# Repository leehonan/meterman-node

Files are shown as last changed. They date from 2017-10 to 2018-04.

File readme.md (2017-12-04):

# Meterman MeterNode

This repo contains PCB designs and firmware for a low-cost, low-power, wireless LED pulse meter node.  It was designed to read and transmit energy consumption from an electricity smart meter LED pulses, but could be used for other LED pulse counting applications.  

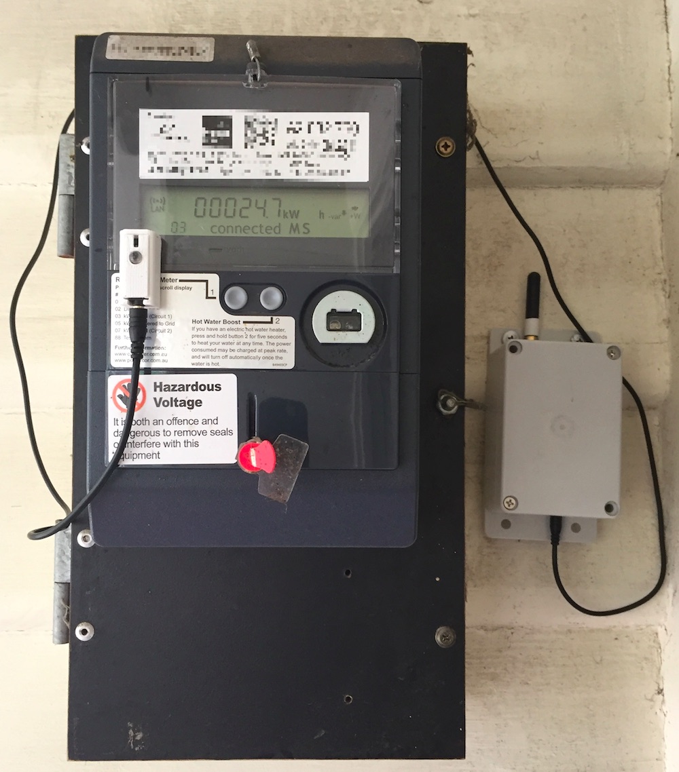
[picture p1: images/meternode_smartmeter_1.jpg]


This 'MeterNode' is part of a basic electricity monitoring system described at http://leehonan.com/meterman.  The 'MeterMan' system consists of:

* One or more MeterNodes, transmitting energy consumption at set intervals using sub-GHz packet radio (RFM69 @ 434/868/915MHz).

* A [Gateway](https://github.com/leehonan/rfm69-pi-gateway), being a Raspberry Pi 'Hat' that bridges the RFM69 network to a Raspberry Pi's UART Serial interface.

* A [Server](https://github.com/leehonan/meterman-server) that runs on the Pi, maintains energy consumption data, and provides access to this and other operational data through an API, a file journal, and a realtime socket API (socket API is TBD).

## This Repo

This (MeterNode) repo consists of:

* The MeterNode PCB design (authored in KiCad).  This mounts in a small 3D-printed box and is powered by 3xAA Batteries or a DC adapter.  It attaches to a small 'puck' sensor using a 3.5mm audio cable.

* The MeterNode Puck PCB design (also KiCad).

* 3D shape files (.STL) for the puck housing.

* Source code for the MeterNode firmware (AVR C with Arduino extensions).  

All contents are licenced according to the MIT licence.

## MeterNode Overview
The image below shows a partially-populated MeterNode installed in a project box with a 3xAA battery holder (empty space at bottom left due to omitting CT and DC power sub-circuits).

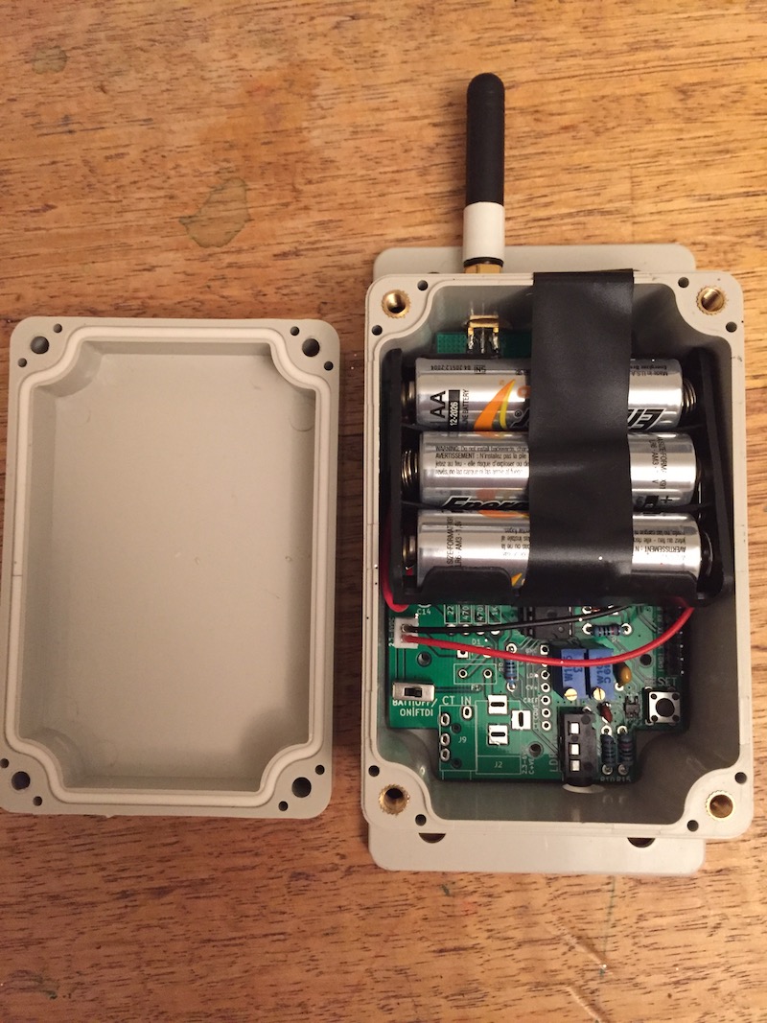
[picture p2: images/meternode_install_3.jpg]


The MeterNode's companion 'Puck' is a peripheral pulse sensor (not really in the shape of a puck - although that was the original idea).  It has a photoresistor on one side, and a red 'super bright' LED on the other.  The photoresistor is placed over the smart meter's 'consumption' LED, and connected to the monitoring MeterNode using a TRS or TRRS 3.5mm cable (with a 3.5mm TRRS jack on each PCB).  

<table><tr>
<td align="center">
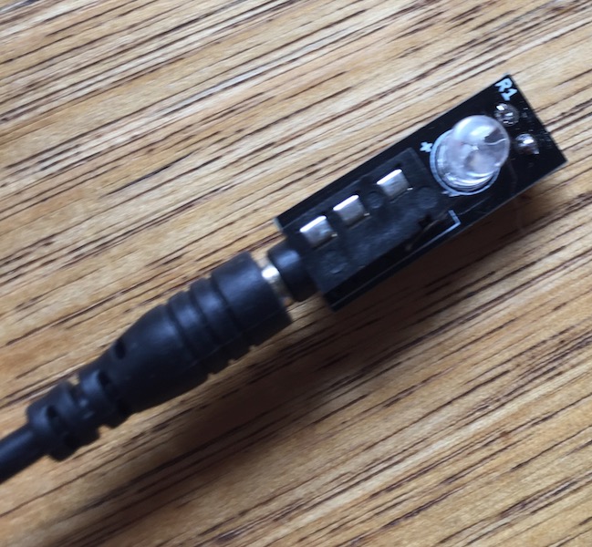
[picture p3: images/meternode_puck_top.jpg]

</td>
<td align="center">
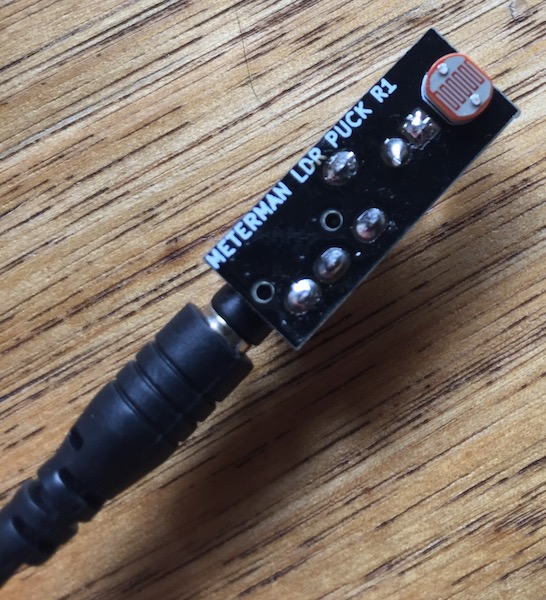
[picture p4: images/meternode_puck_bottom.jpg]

</td>
</tr></table>

The smart meter's consumption LED will pulse on/off as a particular unit of power is consumed (e.g. 1 pulse per watt-hour/Wh) - this varies by meter and is configurable on the MeterNode.  The puck's red LED can flash in unison with the smart meter (off by default to conserve battery).

While there are a number of ways to interrogate a smart meter (e.g. ZigBee, Serial and Optical ports), the approach used is cheap, non-invasive, hacker-friendly, and 'permissionless'.  Zigbee is not cheap, not hacker-friendly, and requires multiple permissions (including a Zigbee production cert and utility device authorisation).  Optical ports vary by meter and are usually password-protected.  Many meters do not have serial ports.

Later iterations may include direct wired metering ('behind' the smart meter) and additional CT clamps.

The MeterNode itself comprises:
* A DC power sub-circuit, switchable between battery/DC jack (3VDC to 5VDC) and FTDI (or off if no FTDI connection).  Uses a MCP1700 regulator to supply 3.3VDC.  Includes an upstream voltage divider for reading VIN or battery voltage (giving an indication of the battery's remaining charge).

* An ATMega 328P MCU sub-circuit, along the lines of common 'minimal low-power Arduino' circuits.  FTDI Header for programming and control.

* A PCF2123 low-power RTC.

* A radio sub-circuit with an RFM69W module.  The design uses an RP-SMA connector, but the PCB also supports uFL or a wire antenna.

* A sub-circuit to integrate the Puck, with a nano-comparator to give a definitive low/high signal to the MCU.  Because this is a slow-moving signal a Schmitt Trigger is used to avoid oscillation (through hysteresis).

* A sub-circuit to integrate a CT clamp, as used by [OpenEnergyMonitor's emonTX](https://github.com/openenergymonitor/emontx3).  This may be left unpopulated and is probably not practical to use if mounting next to a smart meter which tends to be outside and some distance from the distribution board/panel, which is typically indoors (unless running a long cable to the Puck).

The following images show a fully-populated MeterNode, with a DC jack and CT Clamp, alongside a partially-populated MeterNode with neither.

<table><tr>
<td align="center">
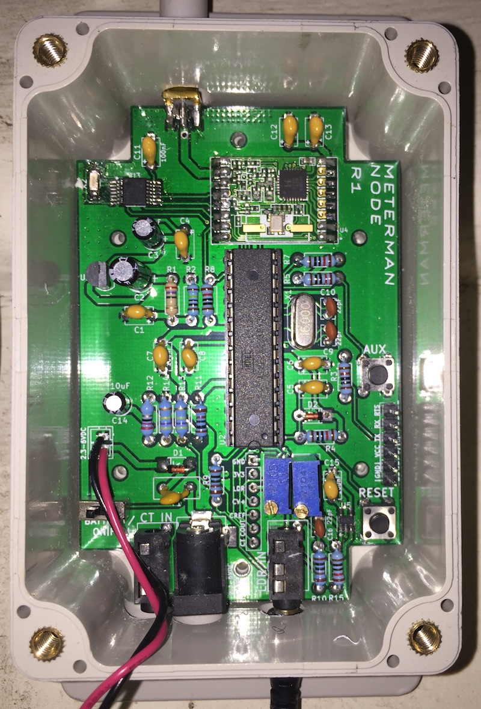
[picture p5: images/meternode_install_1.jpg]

</td>
<td align="center">
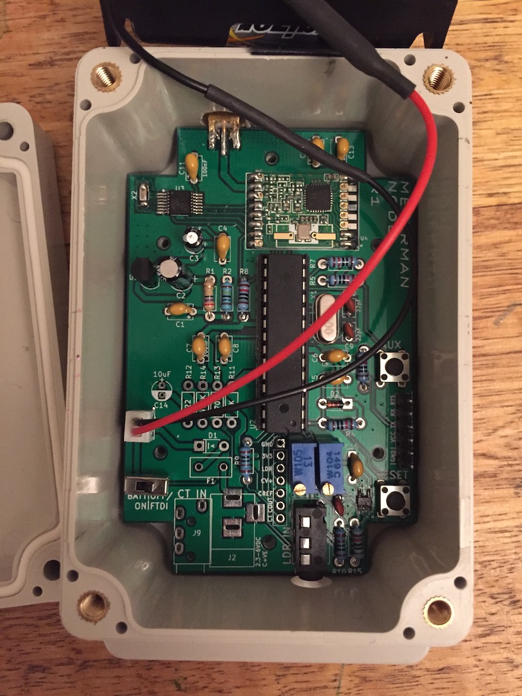
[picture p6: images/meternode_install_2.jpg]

</td>
</tr></table>

## Operation

The MeterNode 'sleeps' in normal operation (consuming about 80uA/microamps), with the MCU waking on an interrupt to record each meter LED pulse and send/receive messages as dictated by configurable timers.  

Given that it wakes/sleeps sporadically, the MeterNode initiates all two-way communication with the Gateway.  Configuration/control instructions to the MeterNode are effectively queued at the Gateway and despatched to the MeterNode when it requests 'Gateway Instructions' (GINR message).  While these instructions are usually polled for at a 'lazy' rate (e.g. every ten minutes), an aggressive polling instruction (GITR message) can be sent to cause the MeterNode to temporarily poll more frequently (e.g. every 30s for 5 min).

The Meternode's operation follows a loop:

* Wake up when an interrupt is triggered by an LED pulse. (At boot the Meternode will stay awake for 15s).

* Log the LED pulse with a timestamp from the onboard RTC, flashing the puck LED if configured.

* Check whether the current metering interval has expired (e.g. 30s), and if so, close it and begin a new one in the metering ring buffer (with a current reading from the CT clamp if configured).  Also check whether a 'meter update' message needs to be sent to the gateway.

* Check whether timers have expired for other periodic tasks, such as synchronising the RTC, adjusting Radio TX Power to fit target RSSI, or getting Gateway Instructions.  

* If required, check for an instruction from the gateway (passing status info such as battery voltage in the request) and process it.

* Sleep until the next LED pulse.

### Metering Approach & Limitations

The MeterNode simply counts consumption LED pulses, and records these against interval entries, with timing according to its onboard clock (RTC).  The pickup/counting is 100% accurate if the sensor is setup properly and not subject to extreme light interference.  A cumulative meter value is stored and transmitted in each message, allowing for interval update message failures.

The MeterNode can be set to a notional 'base value' to track the smart meter being monitored.  This allows for easy verification that the MeterNode is tracking accurately, although it is difficult to align the two exactly as the smart meter will only display a coarse value (e.g. to the nearest 100 Wh).  This can be set using a serial command or radio message as described below.

In normal operation, the MeterNode will create/close interval entries every n seconds, and despatch these in 'meter update' messages to provide energy consumption snapshots.

In the unlikely case that the smart meter is dormant (i.e. 0Wh consumption), the MeterNode will sleep ad infinitum, but then wake and send an update message that may have skipped previous intervals.

The MeterNode will execute a 'rebase' any time its clock changes, or the meter's base value is reset.  This results in a 'rebase message' which instructs consumers that the time/energy basis of the accumulation meter has changed.  Rebases will occur when:

* The MeterNode is booted.

* The RTC is set.

* The base value of the accumulation meter is changed.

* The accumulation meter cycles from its maximum value (4.2 GWh) to 0 Wh.  (Note that smart meters themselves are occasionally zeroed/cycled arbitrarily, e.g. by remote firmware upgrades.)

The MeterNode cannot:
* Guarantee a message element for every 0Wh consumption interval, or indeed guarantee that any message will be sent/received successfully.

* Guarantee a rebase message will be received.  Consuming applications should alert on large increases or reversals in time/meter values.

* Maintain meter readings between reboots (that would necessitate constant writing to EEPROM, which degrades after ~100K writes).

* Check itself against the meter being tracked.

* Confirm that it is alive, or detect issues with its sensor (as it will be asleep) - although this can be done at the consuming node(s).

### MeterNode Hardware Interface
The MeterNode PCB has the following switches, buttons, headers, and adjustable components.  These are shown below.
<table><tr>
<td align="center">
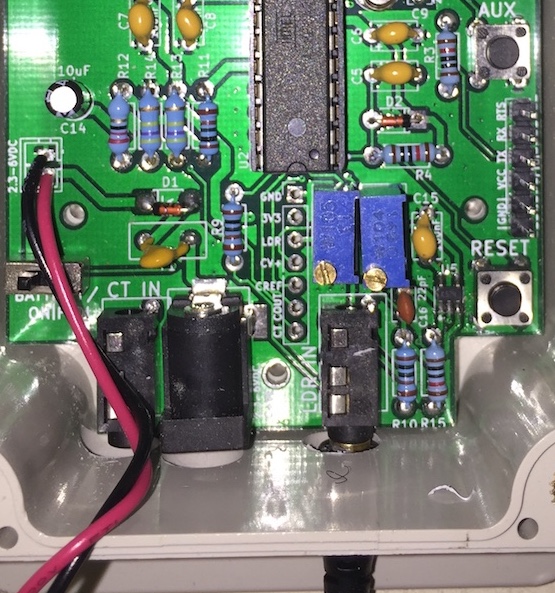
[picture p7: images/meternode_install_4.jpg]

</td>
<td align="center">
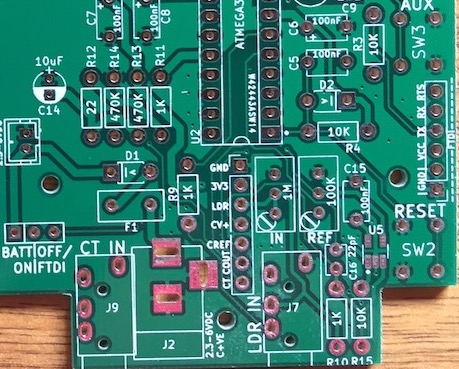
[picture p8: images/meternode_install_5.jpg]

</td>
</tr></table>

* A VIN switch that toggles between either battery/DC-in or FTDI/Off.  A battery must not be connected at the same time as a DC adapter, but either can be connected at the same time as a FTDI adapter.  If the switch is in the FTDI/Off position but FTDI is not connected the device will be off.  Conversely if the switch is in the battery/DC-in position but a FTDI adapter is connected, power will be drawn from the battery/DC adapter (with other FTDI functions working as normal).

* A MCU Reset button that reboots the MCU.

* An auxiliary button that is used to either toggle sleep mode or enable a temporary alignment mode:

    - If sleeping, any detected press will set sleep off (3 flashes).
    Release as soon as flashing starts.  Will need to hold down until
    interrupt fires (i.e. watched LED pulses).

    - If not sleeping, short press of < 1s will set sleep on (5 flashes).
    Release as soon as flashing starts.

    - If not sleeping, long press of > 3s will start a 60s adjustment mode (7
    flashes) that forces meter LED rate to 1, and time to 0 (mimic watched
    LED).  This will cause the Puck LED to flash in unison with the smart meter's LED for 60s.

* An FTDI header for use with a USB-FTDI adapter.  This is used to upload firmware and also to interact with the MCU directly over a serial connection (viewing events and using the MeterNode's command protocol to view information and change settings).  Firmware can be uploaded using avrdude directly, or via an IDE (such as platform.io).  Depending on the adapter and client software uses, this may reset the MCU.

* A breakout header that is used for setup and diagnosis, typically with a multimeter.  The positions are described below and pictured earlier:

| Position | Description |
| :--- |:---|
| GND | DC Ground. |
| 3V3 | 3.3VDC from regulator.  |
| LDR  | Output from LDR, fed to Comparator via Schmitt Trigger (from which it is segregated by a 1K resistor). <br> Tuned using the LDR trimpot, typically 0.2V to 2.0V (LED on-off). |
| CV+  | V+ input to Comparator, affected by Schmitt trigger feedback. |
| CREF  | LDR Comparator Reference Voltage (ideally 1.5V).  Set using the REF trimpot. |
| COUT | Output from Comparator.  Should be Low (0V) or High(3.3V).  Goes to MCU D3 (interrupt 1). | 
| CT | Output from CT clamp circuit.  Value from 0V to 3.3V is linear representation of RMS current.  Goes to MCU A1.  |

### Puck Setup
The setup and calibration of the light-dependent resistor (LDR) is critical.  It should be positioned directly over the LED being monitored, and shielded from ambient light.  It is best installed using double-sided tape to affix the base of the housing to the smart meter, ensuring that the LED is centred in the base's hole (that the photoresistor 'looks through').  See the assembly instructions below for more detail.

While the approach used is not overly sensitive to ambient light (compared with photodiodes, or an LDR without a comparator and schmitt trigger), minimising ambient light will increase the range around the comparator's reference/trigger point.  In practice the design used can work with some intrusion of relatively bright light (e.g. direct sunlight on a meter), but only up to a point.

With the MeterNode on and the puck installed, connected:
* Connect a multimeter to GND/CREF.  Adjust to 1.5V using the REF trimpot.

* Move the positive probe to the LDR breakout header position.  Adjust the LDR trimpot until you see a substantial swing between low and high states (e.g. 0.2V to 2.0V) around CREF.  A high level of ambient light may boost the lower value.  The trimpot's effective zone if fairly small - it will appear to be stuck high or low for many turns, and then suddenly become responsive.

* Move the positive probe to the COUT breakout header position.  This should be swinging between 0V (low) and 3.3V (high) to indicate reads.

Given that the actual hystersis gap of the comparator circuit is ~10mV, in theory a small swing either side of CREF will be sufficient to produce a definite high/low reading.  However, using a very wide value will compensate for fluctuations in ambient light and other factors.

### CT Clamp Setup
The design and firmware assumes a YHDC SCT-013-000 CT clamp, which has 100A max current.

A 22 Ohm burden resistor is used to output a voltage proportionate to CT clamp's secondary coil voltage.  

This configuration can measure up to 97A (23.3kW @ 240V).  The minimum reliable detection current is 0.3A, with potential for noise below this.  The constant CT_IRMS_HIGH_PASS is used to set a high-pass filter (0.3A by default).

WARNING: Be careful not to unplug the CT clamp from node while it's clamped to a 'live wire'.  It may shock.  There is a protection diode in the clamp, but its protection shouldn't be relied upon.

### Uploading Firmware
Firmware is uploaded using avrdude (alternately through an IDE such as atom/platform.io, the Arduino IDE may work too).  For an FTDI adapter with Id A403JXEV on OSX or Linux the command will be something like (change device and path to firmware):

```
sudo avrdude -c arduino -p atmega328p -P /dev/cu.usbserial-A403JXEV -b 115200 -U flash:w:/home/tmp/firmware.hex
```

### Serial Communication & Console
A serial connection can be made using a baud of 115200bps, 8N1 (8 data bits, no parity bit, 1 stop bit).  E.g. with minicom and a FTDI adapter at /dev/cu.usbserial-A403JXEV:

```
sudo minicom -b 115200 -o -D /dev/cu.usbserial-A403JXEV
```

Note that connecting or disconnecting a FTDI adapter will not cause a reboot when running on battery power.

The following commands are available through the serial console (case-insensitive):

| Command | Description |
| :--- |:---|
| help | Prints a list of commands. |
| z  | Toggles sleep on and off. |
| ctcl | Toggles CT Clamp on and off. |
| dump  | Prints (dumps) MeterNode config and status to the console.  |
| rcfg | Reset Config.  Resets configuration values stored in EEPROM to defaults and re-applies these.  |
| time | Prints current time from RTC. Set using time=[seconds since UNIX epoch, UTC] |
| logl | Prints log level - ERROR, WARN, INFO, DEBUG.  Set with logl=[log level]|
| ekey | Prints encryption key (16 byte AES) used by network participants for radio comms.  Set with ekey=[encryption key], e.g. ekey=CHANGE_THIS_ASAP|
| neti | Prints MeterNode's Network Id comprised of octets akin to an IP address but with an extra subnet (as the 4 octets define a subnet, with node addressing within this).  Set with neti=[network_id].  At least two octets need to be non-zero so 0.0.1.1 is the 'lowest' usable network subnet.  E.g. neti=0.0.1.1|
| gwid | Prints the 'node id' for the gateway.  This should be 1 by convention, but can be any unallocated address from 1 to 253. Set with gwid=[gateway Id]|
| noid | Print/set MeterNode's node id (set with noid=[node id]).  2-253 by convention. |
| trss | Print/set target RSSI for auto-tuning (set with TRSS=[target RSSI]).  Range is -100 (no signal) to 1 (almost no noise), 0 is disable auto-tuning. -75 is a reasonable value. |
| txpw | Print/set transmission power (set with TXPW=[tx power in dBi]).  For RFM69W range is -18 to +13, for RFM69HW is -14 to +20. Higher values will use more power. |
| mtrv | Set meter value (set with MTRV=[meter value]) in Wh.  May be used to track electricity meter's register. Will overflow and cycle to 0 at 4.2 billion Wh. |
| mtrr |  Print/set meter impulse per kWh rate (set with MTRR=[impulse count]).  E.g. mtrr=1000. |
| mtri |  Print/set meter interval (set with MTRI=[meter interval in sec]).  Up to 255. |
| test |  Toggle test mode, forcing sleep off and simulating watched meter LED pulses. |
| ledr |  Print/set puck LED rate (set with LEDR=[rate per meter LED]).  This is the number of 'watched meter' LED flash/pulses per 'puck' LED flash in response.  E.g. could flash once every 10 to consume battery.  0 means LED is disabled (except to indicate boot). |
| ledt |  Print/set puck LED time (set with LEDT=[time in millis]).  Is max duration of each LED pulse emitted by the puck in millis. Setting to 0 will cause to flash in unison with meter.  Maximum of 3000, but puck LED will always go low/off on falling edge of meter's pulse. |

###  Radio Protocol
The MeterNode uses the [RadioHead Library](http://www.airspayce.com/mikem/arduino/RadioHead/), and 'Reliable Datagrams' for all messaging.

Messages are AES-128 encrypted, with a maximum payload of 61 bytes.  Fields are comma-delimited, records semi-colon-delimited (only used for meter updates).

In addition to being encrypted, messages are contained within the 'subnet' created by the Network Id setting (e.g. 0.0.1.1), with each node having an identifier between 1 and 254 (255 is broadcast).  By convention I use 1 for a gateway, with nodes beginning at 2 (e.g. 0.0.1.1.2).

All datetimes are seconds since UNIX epoch (01/01/1970 00:00:00 UTC).

| Message | From | To | Description|
| :--- |:---| :--- |:---|
| Meter Update - with Current | node | gateway | Communicates the _n_ most recent closed meter intervals to the Gateway, with the meter's previous accumulated value (e.g. 100,000Wh), consumption in each interval (e.g. 15Wh), and an 'on the spot' current measurement taken at the end of the interval. <br> Format: `MUPC,<last_entry_finish_time>,<last_entry_meter_value>,{2..n of <interval_duration>,<interval_value>,<spot_rms_current>}` <br> Where in this case meter and interval values are in Wh (configurable) - with last entry value being a baseline accumulation entry (the last entry broadcast by the MeterNode) and interval values being increments to that, interval duration in seconds, current in Amps. <br> E.g.: `MUPC,1496842913428,18829393;15,1,10.2;15,5,10.7`  <br> Due to message size constraints this will contain no more than 2 interval entries.|
| Meter Update - no Current | node | gateway | As above, but without current measurements. <br> Format: `MUP_,<last_entry_finish_time>,<last_entry_meter_value>,{2..n of <interval_duration>,<interval_value>}` <br> E.g.: `MUP_,1496842913428,18829393;15,1;15,5;15,2;16,3` <br> The number of interval entries in each message can be set by a firmware constant, with 3 or 4 being a reasonable value.|
| Meter Rebase  | node  | gateway  | Sent at boot or whenever meter value or RTC adjusted to notify the gateway of step-changes in time or meter value.  'Re-baselines' the meter, such that all prior messages should be regarded as nominal/unreliable for determining an accumulation value. <br>Format: `MREB,<meter_time_start>,<meter_value_start>` <br> E.g.: `MREB,1496842913428,18829393`|
| Gateway Instruction Request  | node  | gateway  | Instruction Request to Gateway, including node status data. <br>Format: `GINR,<battery_voltage>,<uptime_secs>,<sleeptime_secs>,<free_ram>,<last_rssi>,<puck_led_rate>,<puck_led_time>,<meter_interval_time>,<meter_imp_per_kwh>`<br>E.g.:`GINR,4300,890000,555000,880,-80,10,100,5,1000` |
| Meter Instruction - Set Interval  | gateway  | node | Set accumulation meter interval. Note all such messages from the Gateway inform the node of the last RSSI for that node at the gateway (for use in TX Power auto-tuning).  <br>Format: `MINI,<new_interval>,<last_node_rssi>`<br>E.g.:`MINI,5,-70`  |
| Meter Instruction - Set Temporary Polling  | gateway  | node | Request from Gateway to temporarily increase GINR polling rate for a specified duration (secs). <br>Format: `GITR,<new_rate>,<duration>,<last_node_rssi>`<br>E.g.:`GITR,30,600,-70` |
| Meter Instruction - Set Value  | gateway  | node | Set accumulation meter value. <br>Format: `MVAI,<new_meter_value>,<last_node_rssi>`<br>E.g.:`MVAI,120000,-70`  |
| Meter Instruction - Set Puck LED  | gateway  | node | Set Puck LED pulse rate and duration. <br>Format: `MPLI,<led_pulse_rate>,<led_pulse_duration>,<last_node_rssi>`<br>E.g.:`MPLI,1,500,-70`  |
| Meter Instruction - 'No Op'  | gateway  | node | 'No op' ACK to GINR, provides RSSI for auto-tuning. <br>Format: `MNOI,<last_node_rssi>`<br>E.g.:`MNOI,-70`  |
| Clock Sync Request | node | gateway  | Clock Sync Ping Request to Gateway. <br>Format: `GMSG,<message>`<br>E.g.:`GMSG,BOOT v2. Flags: EX` |
| Clock Sync Response | gateway  | node | Clock Sync Ping Response from Gateway, used to sync local RTC. <br>Format: `PRSP,<request_time_node>,<current_time_gateway>,<align>,<last_node_rssi>`<br>E.g.:`PRSP;14968429155328,1496842915428,1,-70` |
| General-Purpose Message  | any  | any  | Broadcast to all devices in network.  Used to communicate boot event. <br>Format: `GMSG,<message>`<br>E.g.:`GMSG,BOOT v2. Flags: EX`|

**Interpreting Meter Updates**

The Meter Update Message should be interpreted as follows:
* Times are **inclusive**.  So consumption of 10Wh per 30s interval over 2 minutes from 10AM would be treated as:
    ```
    10:00:00 - 10:00:29 = 10Wh
    10:00:30 - 10:00:59 = 10Wh
    10:01:00 - 10:01:29 = 10Wh
    10:01:30 - 10:01:59 = 10Wh
    ```     

* last_entry_finish_time and last_entry_meter_value is for the last entry in the last MUP communicated by the meter node.  So for the example above, at 10:00:00 the interval entry ending at 09:59:59 was closed, and sent in a MUP with the 3 entries that preceded it.  At 10:00:00, 09:59:59 has just expired with an accumulated meter value of 5622Wh - these will form the baseline for the next MUP.

* Given this example, the next MUP is sent at 10:02:00 will be as follows:

    ```
    MUP_,1511737199,5622;30,10;30,10;30,10;30,10;
    ```

* Of course a MUP could be missed (without a rebase).  The consumer should take account of the baseline value, and not merely store/process the interval entries.    

### Power consumption & battery life
When awake the MCU consumes about 7mA/milliamps, and depending on radio config about 30-50mA for a few milliseconds when transmitting messages.  

In typical use, the MeterNode spends >=99% of its time asleep (affected by meter entry interval lengths).  

3xAA batteries should last 6-12 months with infrequent communication (TBC), although theoretically would last several years if sleeping perpetually, about 1-2 weeks if never sleeping.  A conservative meter interval (e.g. 60s), with 4 entries per message, and a long GINR polling interval (e.g. 600s) is recommended.

The MeterNode will function while battery voltage is >= 2.8V (or 2800mV as reported in GINR messages) - with the 328P MCU being the limiting factor, ideally supplied >=3.3V.  Unfortunately the regulator used (MCP1700) is only a step-down regulator - it cannot step-up lower voltages.  It is otherwise an excellent choice for this application.  Consuming applications should set a battery replacement alert threshold, e.g. 3.0V.

Using the puck LED (which consumes about 1mA) to indicate a meter LED flash will reduce battery life significantly - this should be minimised to testing, e.g. to check alignment (which can be performed more accurately with a multimeter).

## Implementation - MeterNode Firmware
For simplicity, the firmware is implemented as a single C++ program (no header file), although it will need supporting libraries to compile.  There is some redundancy versus the companion gateway firmware - the common components may be moved to a library.  Some Arduino library features are used.

The firmware requires a 328P that has been flashed with Optiboot.  It uses practically all of available program flash memory.  If you are hacking or debugging you'll need to comment out a block of code to make space - e.g. the checkButton() or checkTestMode() methods.

Depending on configuration, about 380 bytes RAM will remain free at runtime (on average, of 2K).  

There are a number of configuration settings at the beginning of the source code.  Particular attention should be paid to the 'Main Config Parameters'.

Note that a version is set in the firmware, and broadcast on boot.

The code is fairly well-documented so isn't covered further here.

## Implementation - PCBs & Cases

The MeterNode PCB measures 60x92mm and is designed to fit a widely-available [100x68x50mm 'project box'](https://www.banggood.com/White-Plastic-Waterproof-Electronic-Case-PCB-Box-100x68x50mm-p-948109.html), shown below.

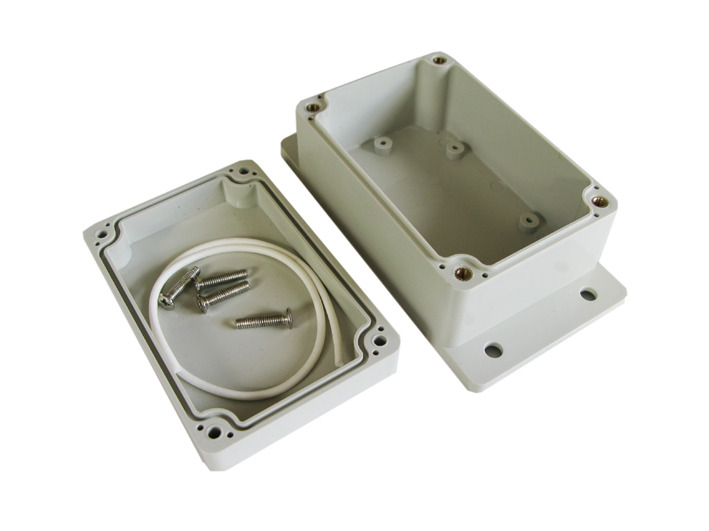
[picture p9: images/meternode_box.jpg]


The MeterNode's companion Puck PCB measures 15x20mm and can be mounted in a 3D-printed case (also in this repo).  The puck can be easily aligned with the meter's consumption LED by adhering the base/case only (positioning its hole directly over the LED) before completing the assembly.

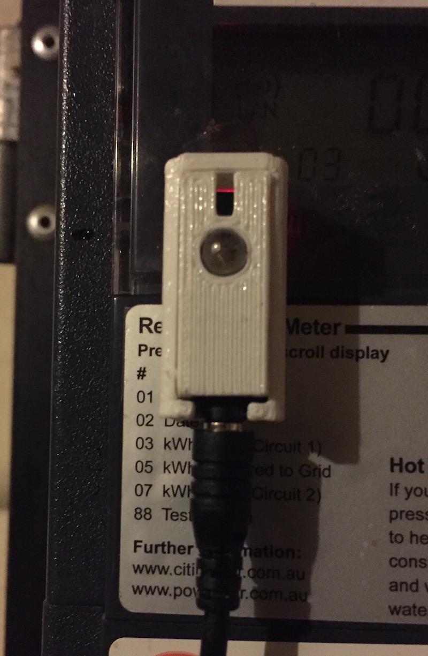
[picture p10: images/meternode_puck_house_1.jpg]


The images below show regular pucks both assembled and disassembled, along with an alternate puck configuration, where the black 'collet' piece shown (.STL included) can be used to position the LDR sensor in tight positions.  The protruding arm is used to adhere the sensor (e.g. using double-sided tape).  The particular meter that necessitated this was the iCredit 500 which has its LED tucked into a tight corner.

<table><tr>
<td align="center">
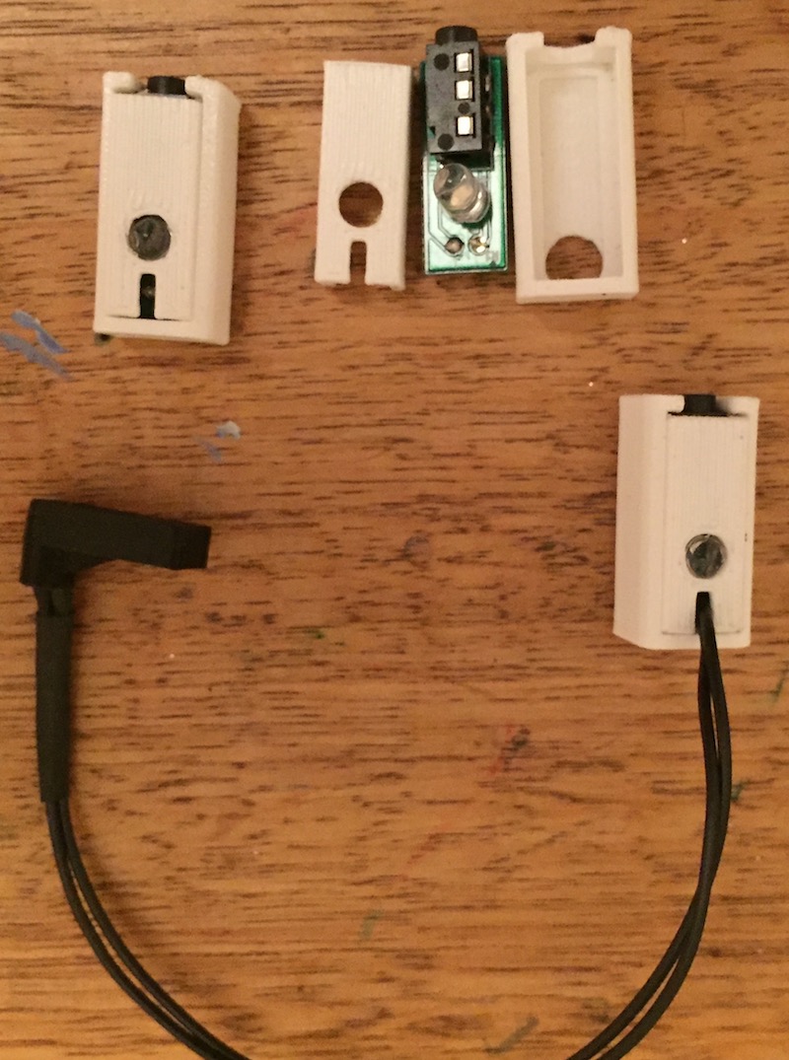
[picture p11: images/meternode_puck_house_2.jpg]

</td>
<td align="center">
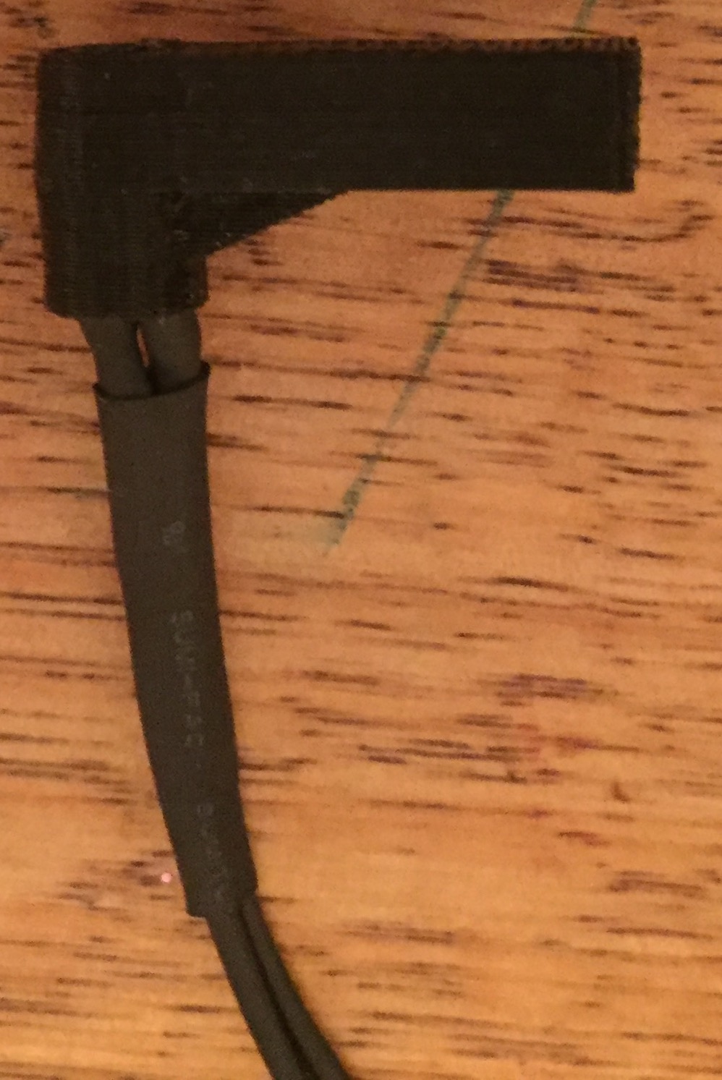
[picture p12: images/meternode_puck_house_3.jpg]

</td>
</tr></table>

The Puck Schematic & PCB is straightforward, so isn't discussed further here - except to mention that care should be taken when soldering as its small size means it can heat up quickly.  

### MeterNode Schematic & PCB

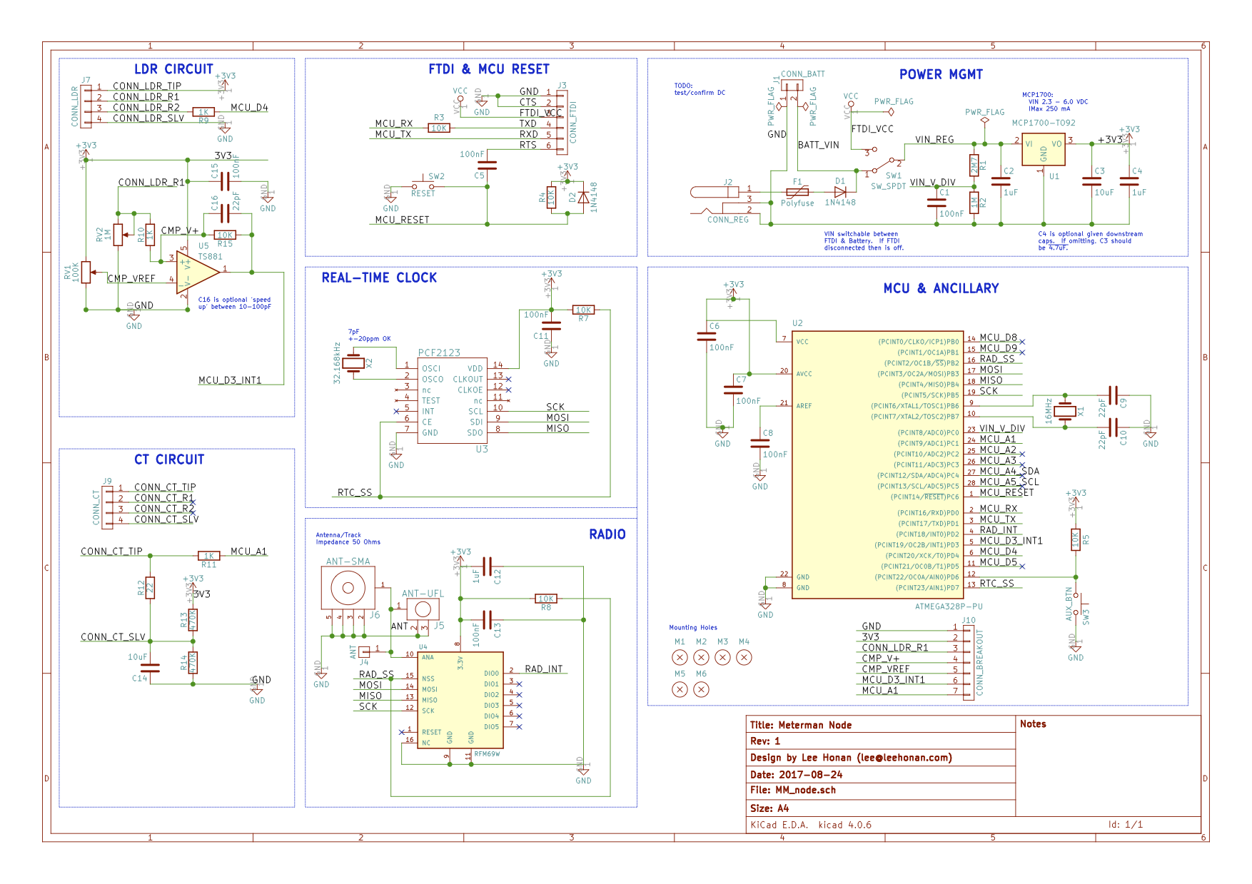
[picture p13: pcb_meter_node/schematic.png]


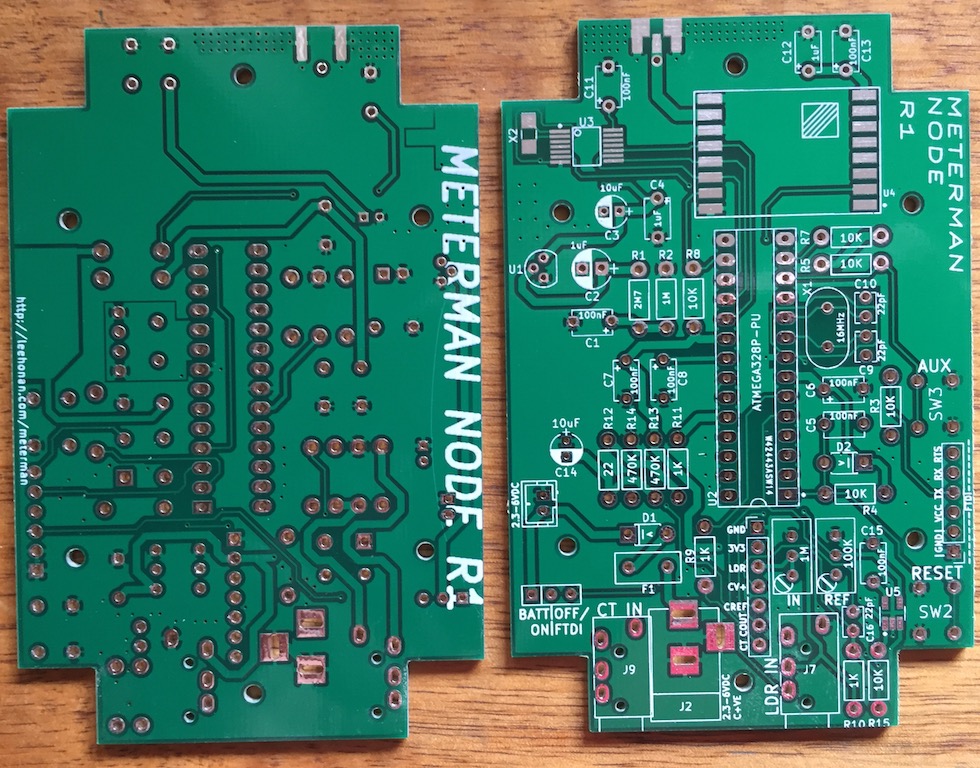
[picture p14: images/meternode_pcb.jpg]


The PCB design minimises the use of SMT components, and uses through-hole instead.  When I originally designed the board I wanted to make it 'hobbyist-friendly' with the only SMT component being the easily-solderable RFM69 and RP-SMA connector.  However in subsequent iterations I added the RTC and comparator, where the best choices were SMT.  This makes the board a hodge-podge, and annoying to make in volume (as I have had to for a few experiments). I may do an SMT-only variant in the future.

Highlights:
* The choice of a photoresistor (LDR) was made after a lot of research and experimentation.  Other projects have concluded that LDRs are too slow, or too affected by ambient light.  I found them to be better in terms of power consumption than alternatives such as photodiodes (about 1/10th), while offering a wide pickup range, and responding 'fast enough' (up to 10Hz).

* A TRRS jack is used for the puck and CT as I had a few hundred of these on-hand.  TRRS cables are unnecessary, TRS can be used.  R1 is not connected on the LDR jack, and R1 and R2 are not connected on the CT jack.
These could be hacked for another application.

* The MCP1700 regulator (3.3V) was chosen due to its low quiescent consumption (1.6uA).  I used a regulator because while the 328P and RTC tolerate VIN ~5.5VDC, the RFM69 has a maximum VIN of only 3.6VDC.  

* A voltage divider (consuming about 1.7uA) is used to measure the voltage input to the regulator - chiefly to allow a basic 'battery meter'.

* Any RFM69W or RFM69HW module will work.  I use the RFM69W because it can be tuned to use less TX power than the RFM69HW.  Given that there is no advantage to mixing radios, I use the RFM69HW on gateways because they are cheaper.

* The RTC used (PCF2123) has low quiescent power consumption (as low as 100nA) and is economical.  It needs a 32.768kHz crystal (7pF, +/- 20 ppm).

* The comparator used (TS881) has low quiescent power consumption (as low as 210nA), is simple to use, and is economical.

* The PCB design also contains a basic AC current sensing circuit for use with an optional CT clamp (around an active or neutral wire).  I used the design from [OpenEnergyMonitor](https://learn.openenergymonitor.org/electricity-monitoring/ct-sensors/how-to-build-an-arduino-energy-monitor-measuring-current-only).  This was a late addition to the design as I wanted to avoid looking at their well-established EmonTx project and see how I went my 'rolling my own'.  When I saw how easy the CT was too add I couldn't resist.  Of course, it will often be impractical to install alongside a smart meter unless running a long cable to the puck (as noted above).

The SMT/SMD components are mostly easy to solder with a decent iron and some flux.  The exception is the PCF2123 RTC, where it is very easy to bridge pins.  I suggest:
* doing SMDs first

* lightly tinning each pad, carefully aligning the IC and soldering a corner pin  

* then applying flux and working your way around

* using a multimeter to test for shorts - via easier to access pads (e.g. for 328P IC)

* inspecting with a loupe or magnifying glass

There are a number of videos on youtube on hand-soldering SMDs.

### Parts List

Includes CT clamp and DC jack.

Approx total is USD$35 (not including labour!).  That assumes you purchase common parts in quantity from Chinese suppliers (e.g. resistors, capacitors).  Otherwise cost will be radically higher.  

| Assembly | Part | Qty | Approx <br>Item Cost<br>(USD) | Comments |
| :--- |:---| :--- |:---|:---|
| Puck | PCB | 1 | $0.50 | E.g. 10 for $5 at PCBWay |
| Puck | Case | 1 | $0.50 | 3D-printed, PLA |
| Puck | LDR | 1 | $0.20 | 5MM Light-Dependent Resistor AKA Photo Resistor.  I use hamamatsu, much cheaper alternatives available. |
| Puck | LED | 1 | $0.02 | Super-bright 5mm, 20mA |
| Puck | TRRS Jack | 1 | $0.05 | PJ320D |
| Puck Cable | 3.5mm TRS or TRRS | 1 | $1.00 | No need to get TRRS |
| CT Clamp | YHDC SCT-013-000 | 1 | $8.50 | 100A version |
| MeterNode | PCB | 1 | $0.50 | E.g. 10 for $5 at PCBWay |
| MeterNode | Case | 1 | $3.50 | From Banggood, cheaper in bulk |
| MeterNode | RP-SMA 3dbi Antenna | 1 | $2.90 | I use higher quality ones via RocketScream, cheaper options available. |
| MeterNode | RP-SMA Connector | 1 | $0.50 |  |
| MeterNode | Battery Holder | 1 | $1.00 | Yet to find with JST connector so solder on cable, or directly to PCB. |
| MeterNode | AA Batteries | 3 | $2.00 | Use best you can afford, e.g. lithium |
| MeterNode | JST-PH connector set | 1 | $0.20 | Can solder wires directly. |
| MeterNode | TRSS Jacks | 2 | $0.05 | PJ320D |
| MeterNode | DC Barrel Jack | 1 | $0.10 | 2.1mm |
| MeterNode | PolyFuse | 1 | $0.20 | 50mA @60V, 5mm spacing |
| MeterNode | MCP1700 Regulator | 1 | $0.50 | 3.3V, TO-92 |
| MeterNode | MCU - ATMEGA 328P | 1 | $1.80 | DIP-28, with holder |
| MeterNode | 16MHz Crystal | 1 | $0.20 | |
| MeterNode | PCF2123 RTC | 1 | $1.20 | TSSOP1 |
| MeterNode | 32.768kHz Crystal | 1 | $0.50 | 7pF, +/- 20 ppm, 3.2x1.5mm SMD |
| MeterNode | RFM69W Module | 1 | $3.00 | SMD |
| MeterNode | TS881 | 1 | $0.65 | SOT-23-5 |
| MeterNode | Resistor - 22 Ohm | 1 | $0.01 | 0.25W |
| MeterNode | Resistor - 1 KOhm | 3 | $0.01 | 0.25W |
| MeterNode | Resistor - 10 KOhm | 6 | $0.01 | 0.25W |
| MeterNode | Resistor - 470 KOhm | 2 | $0.01 | 0.25W |
| MeterNode | Resistor - 1 MOhm | 1 | $0.01 | 0.25W |
| MeterNode | Resistor - 2.7 MOhm | 1 | $0.01 | 0.25W |
| MeterNode | Trimpot - 100 KOhm | 1 | $0.50 | Bourns 3296W knock-off |
| MeterNode | Trimpot - 1 MOhm | 1 | $0.50 | Bourns 3296W knock-off |
| MeterNode | Capacitor - 22 pF | 3 | $0.01 | Ceramic disc |
| MeterNode | Capacitor - 100 nF | 8 | $0.01 | Monolithic, Ceramic |
| MeterNode | Capacitor - 1 uF | 1 | $0.02 | Electrolytic |
| MeterNode | Capacitor - 1 uF | 2 | $0.01 | Monolithic, Ceramic |
| MeterNode | Capacitor - 10 uF | 2 | $0.02 | Electrolytic, 4x7mm |
| MeterNode | Diode - 1N4148 | 2 | $0.01 |  |
| MeterNode | Micro SPST Switch | 1 | $0.15 | 3P |
| MeterNode | 6x6mm pushbutton | 2 | $0.02 |  |
| MeterNode | Pin Header | 1 | $0.02 | 6P, 2.54mm pitch |

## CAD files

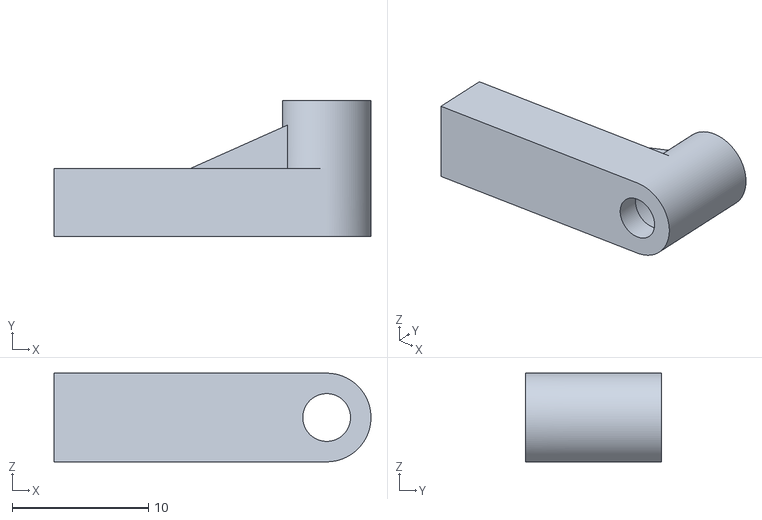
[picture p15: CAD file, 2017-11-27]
pcb_puck/3D parts/Collett.stl
23.2 x 10.0 x 6.50

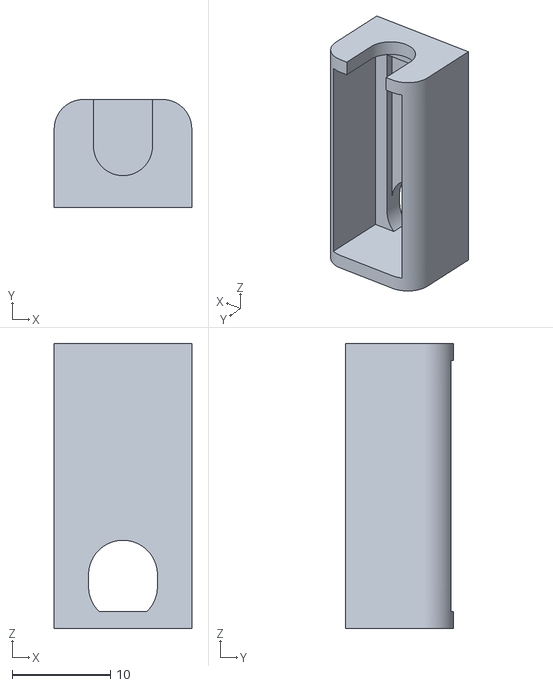
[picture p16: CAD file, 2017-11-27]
pcb_puck/3D parts/Base.stl
14.0 x 11.0 x 29.0

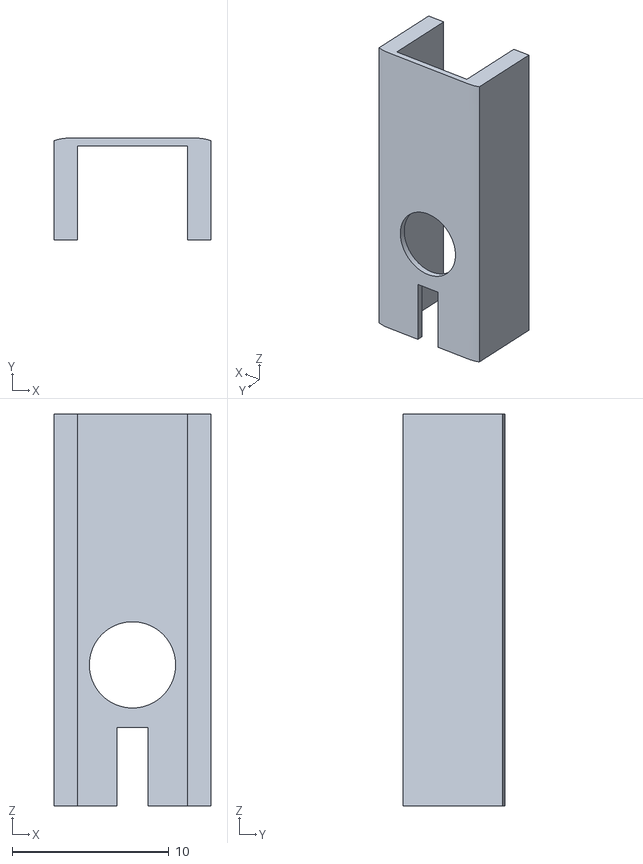
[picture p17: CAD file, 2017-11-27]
pcb_puck/3D parts/Lid.stl
10.0 x 6.50 x 25.0

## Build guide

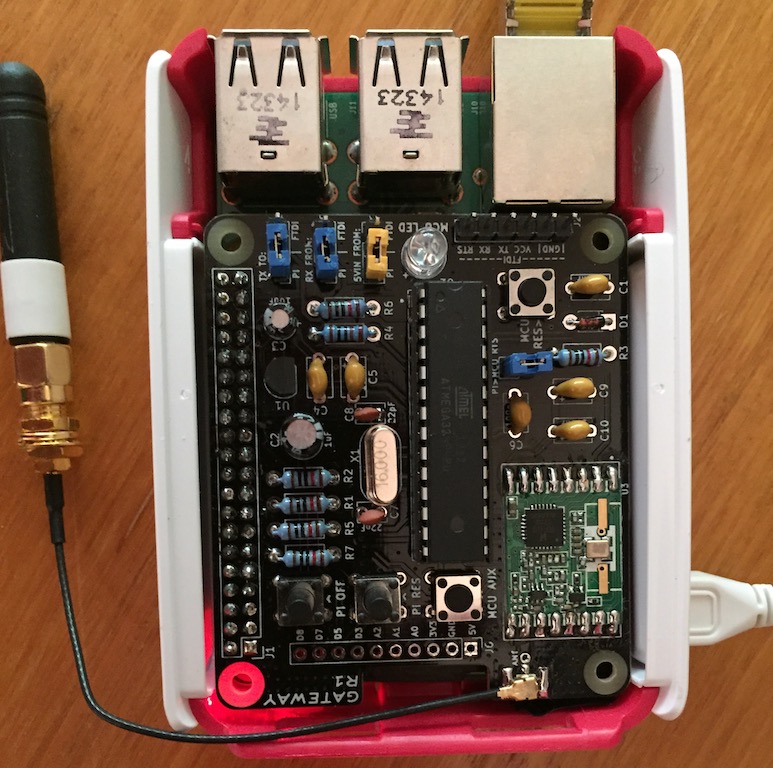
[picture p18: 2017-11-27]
images/gateway_install_1.jpg

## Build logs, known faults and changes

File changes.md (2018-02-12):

# Change Log

Release/revision numbering is major only, no minors - i.e. 1,2,3... not 1.1, 1.2, 2.0, etc.

#### 2017-11-27 R6
* Baseline release to GitHub (from private repo).

#### 2017-11-29 R7
* Changed CT clamp to be enabled/disabled from command line.  
* Various optimisations to cram program into ROM (mostly shortening strings).

#### 2018-01-22 R8
* Changed sscanf calls to use SCNu8 macro for uint_8t vars, SCNd8 macro for int_8t vars

#### 2018-02-06 R9
* Reduced default modem baud rate to 9.6kbps
* Abbreviated some console text to fit MCU when compiled with high power enabled

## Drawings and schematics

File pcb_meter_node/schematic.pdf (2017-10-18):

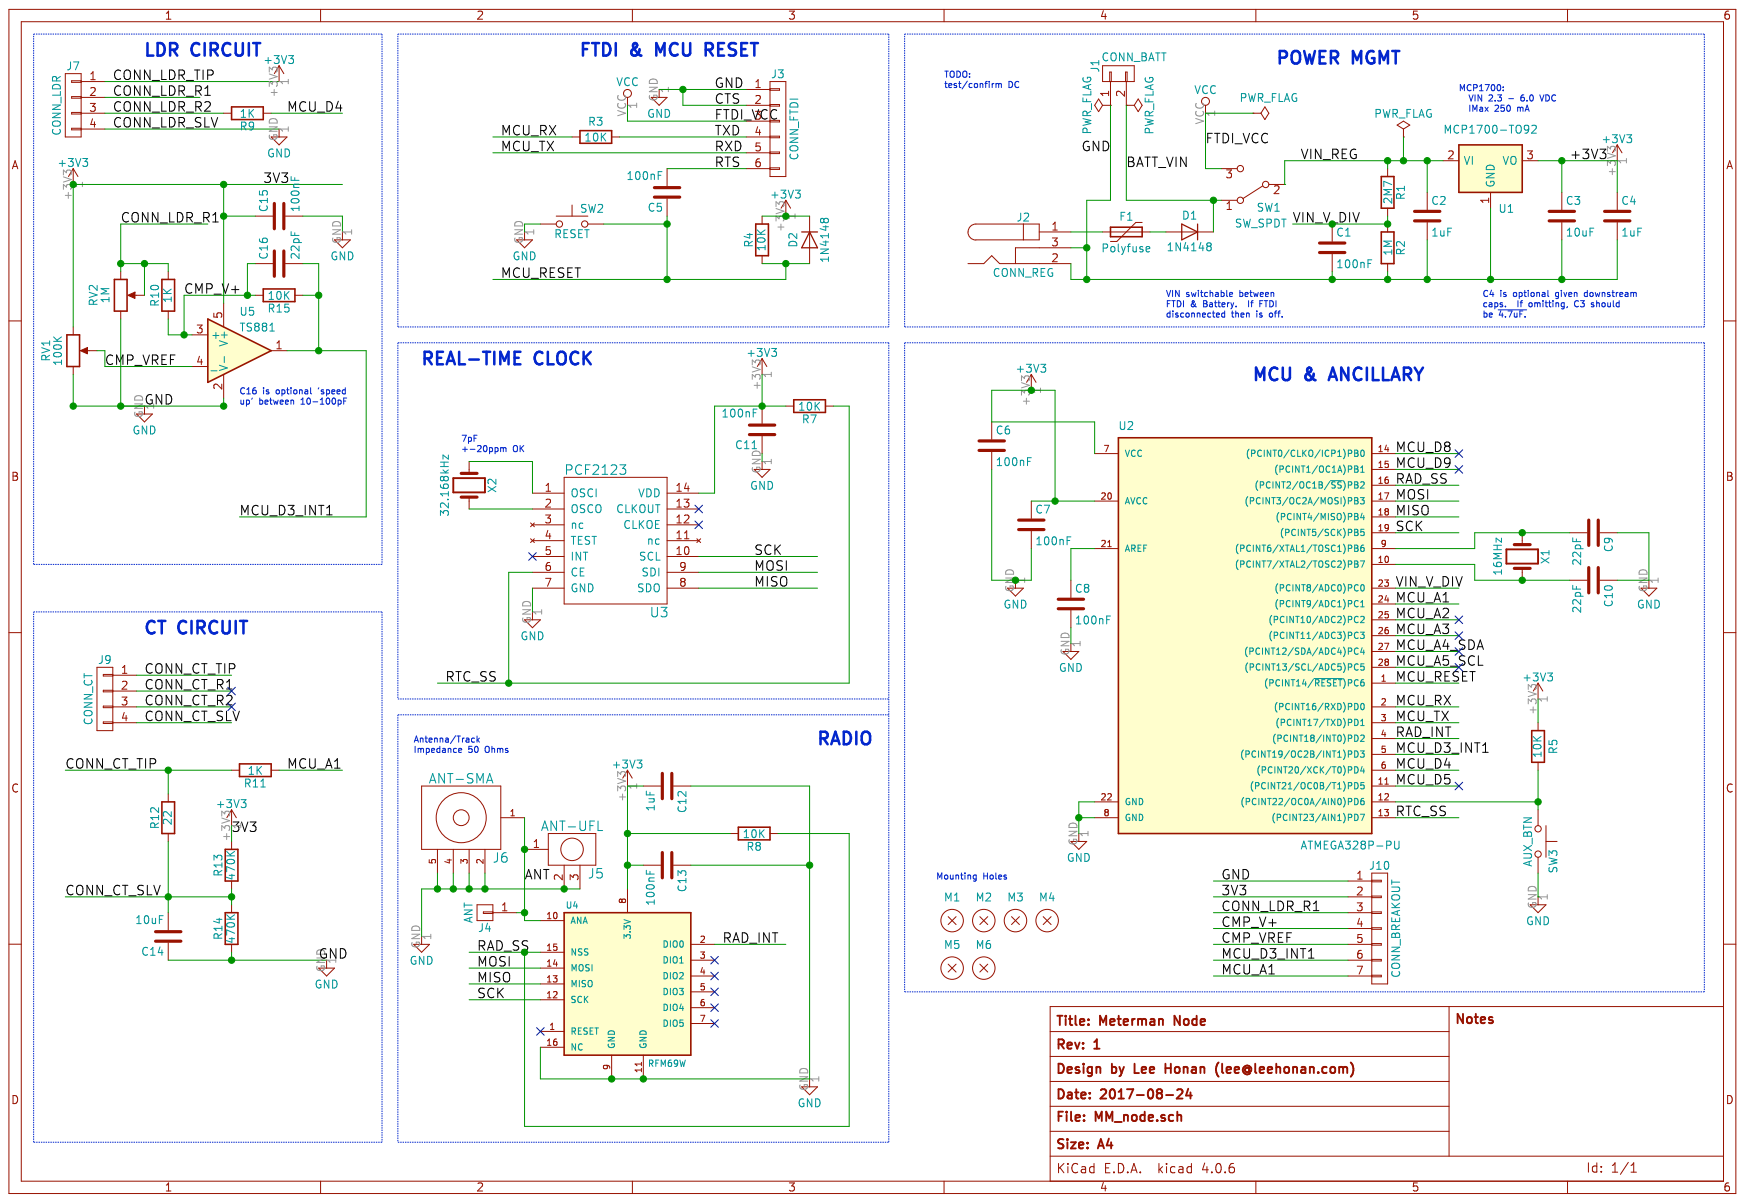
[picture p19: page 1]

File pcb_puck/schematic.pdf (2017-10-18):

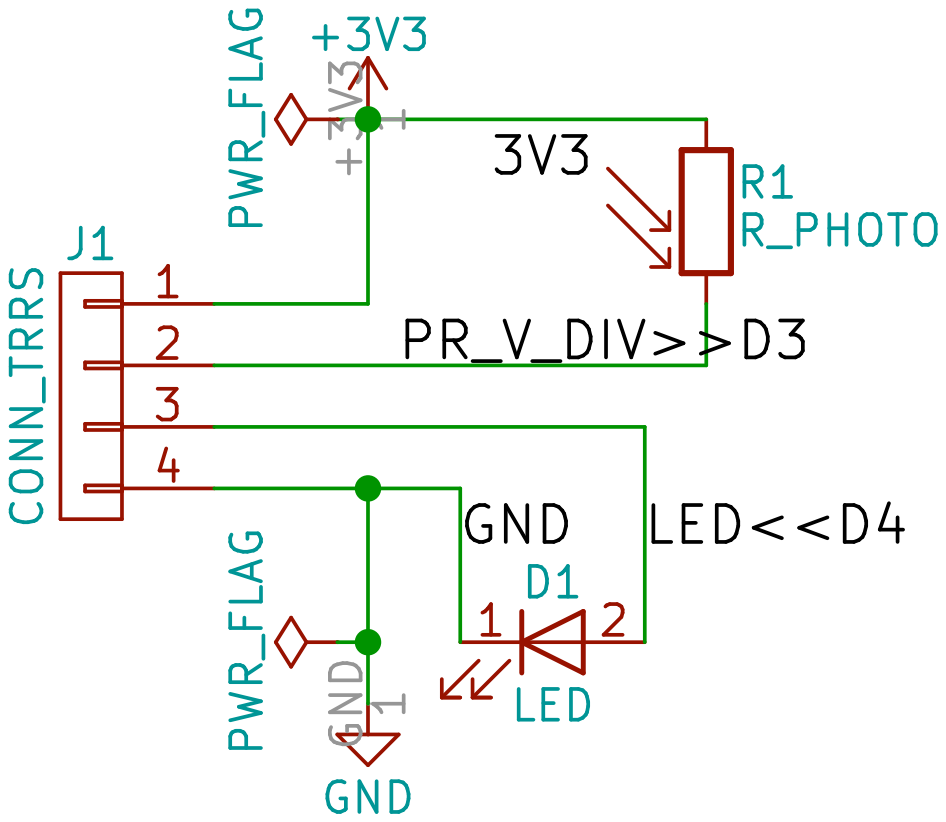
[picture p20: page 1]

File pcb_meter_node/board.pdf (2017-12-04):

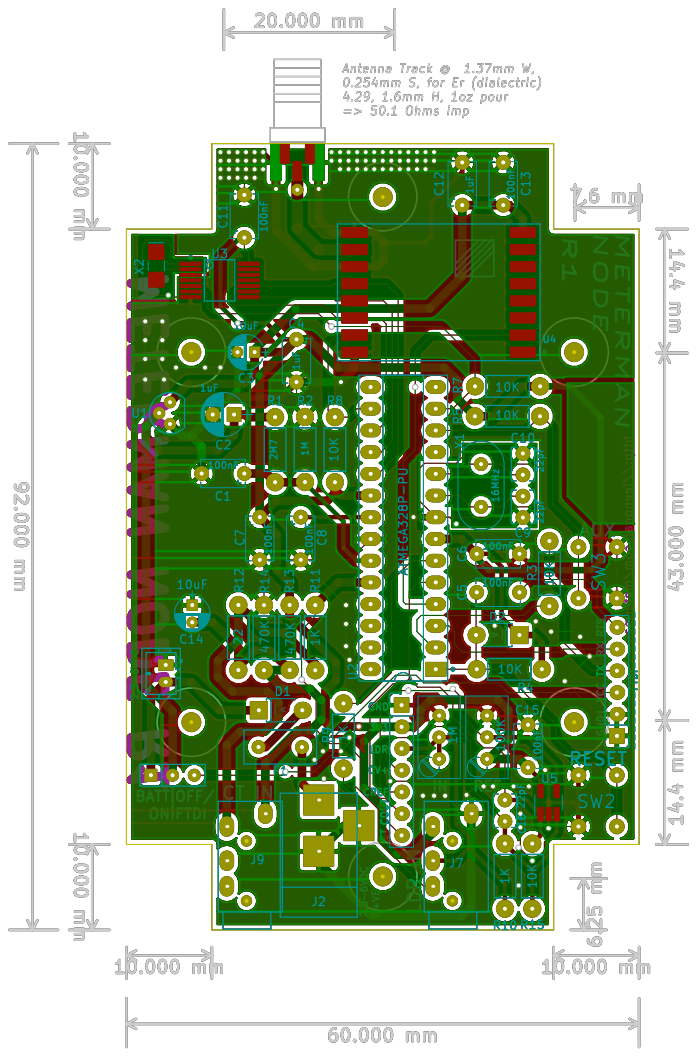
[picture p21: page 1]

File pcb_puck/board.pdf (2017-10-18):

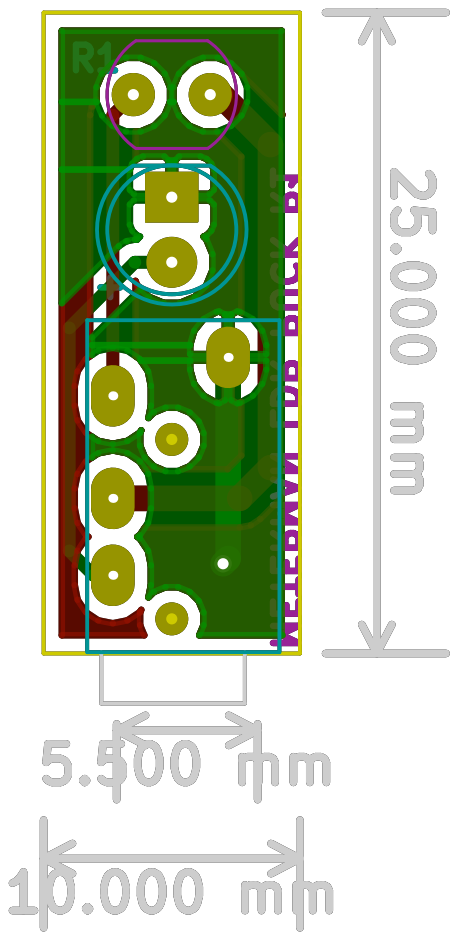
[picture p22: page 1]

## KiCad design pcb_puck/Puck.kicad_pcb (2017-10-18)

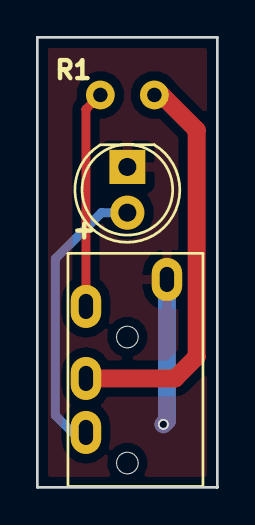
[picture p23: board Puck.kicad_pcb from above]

Board: 2 copper layers, 10.0 x 25.0 mm, 3 parts (1 on the bottom side), 4 nets.

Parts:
D1: LED; LED-5MM
J1: CONN_HORUS; TRRS_Jack
R1: R_PHOTO; Resistor_LDR_5x4.1_RM3

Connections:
+3V3: J1.1, R1.1
/LED<<D4: D1.2, J1.3
/PR_V_DIV>>D3: J1.2, R1.2
GND: D1.1, J1.4

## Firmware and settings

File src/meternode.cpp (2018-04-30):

/**
    =========
    METERMAN METERNODE
    meternode.cpp
    =========

    Operates a 'pulse meter node' that counts and records LED pulses into 'read
    entries', corresponding to a set interval (e.g. a 15s period).  These
    entries are periodically transmitted to a receiver(s) over packet radio. The
    meter node device this code was written for is designed for non-invasive,
    'permissionless' monitoring of electricity smart meters, but the code and
    meter node device could be used to count the pulsing of any LED (with minor
    code changes).  A CT clamp circuit is also included for reading AC current.

    The meter node has a corresponding gateway receiver, which takes the form of
    a Raspberry Pi 'Hat' (daughterboard).  This gateway could aggregate multiple
    nodes. These are part of a basic monitoring system as described at
    http://leehonan.com/meterman.  Repos are at http://github.com/leehonan.

    The meter node can be interacted with over serial (FTDI) and also packet
    radio messages.

    Meter node hardware consists of a custom board with a basic ATMEGA 328P
    circuit, an RFM69 radio, a RTC (PCF2123), battery (or DC adapter) with
    voltage divider, FTDI header, a sub-circuit to integrate a 'puck' that goes
    over the LED being counted, and a CT clamp sub-circuit for AC current
    sensing.  The puck attaches using a cable and consists of a photoresistor
    and a LED that can flash in unison with the smart meter's LED (other modes
    are configurable, including turning this off to conserve battery -
    recommended).

    Uses the following libraries (with licencing):  RadioHead (GPL Version 2
    Licence), PCF2123 (MIT Licence), LowPower (Creative Commons
    Attribution-ShareAlike 3.0 Unported), and EMonLib (GPL Version 3).

    This program is licenced as follows below.

    -----------
    MIT License
    -----------

    Copyright (c) 2017 Lee Honan (lee at leehonan dot com).

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
    THE SOFTWARE IS PROVIDED "AS IS", WITHOUT WARRANTY OF ANY KIND, EXPRESS OR
    IMPLIED, INCLUDING BUT NOT LIMITED TO THE WARRANTIES OF MERCHANTABILITY,
    FITNESS FOR A PARTICULAR PURPOSE AND NONINFRINGEMENT. IN NO EVENT SHALL THE
    AUTHORS OR COPYRIGHT HOLDERS BE LIABLE FOR ANY CLAIM, DAMAGES OR OTHER
    LIABILITY, WHETHER IN AN ACTION OF CONTRACT, TORT OR OTHERWISE, ARISING
    FROM, OUT OF OR IN CONNECTION WITH THE SOFTWARE OR THE USE OR OTHER DEALINGS
    IN THE SOFTWARE.
 */

// *****************************************************************************
//    Main Config Parameters
//    'DEF_*' constants are defaults for configuration variables of the same
//    name. Most of these will be stored to EEPROM and can be updated by
//    serial terminal commands.
//
//    Have minimised use of #DEFINE, #IFDEF etc for easier debugging.
// *****************************************************************************

#include <Arduino.h>
#include <avr/wdt.h>
#include <EEPROM.h>

// http://www.airspayce.com/mikem/arduino/RadioHead/
#include <RH_RF69.h>
#include <RHReliableDatagram.h>

// https://github.com/LowPowerLab/LowPower/archive/master.zip
#include <LowPower.h>

// https://github.com/jvsalo/pcf2123/archive/master.zip
// uses https://github.com/PaulStoffregen/Time/archive/master.zip
#include <PCF2123.h>

// https://github.com/openenergymonitor/EmonLib
#include <EmonLib.h>

static const int8_t FW_VERSION = 10;

// Whether a CT clamp is installed
uint8_t cfgCTEnabled = 0;

// Log Levels
typedef enum {
    logNull = 0,        // outputs to serial regardless of runtime log level
    logError = 1,
    logWarn = 2,
    logInfo = 3,
    logDebug = 4
} LogLev;

// Default runtime log level.
// Can control through serial command, save to EEPROM.
static const LogLev DEF_LOG_LEVEL = logInfo;

// if using HW/HCW module, must set to true
static const bool RADIO_HIGH_POWER = false;     // RFM69W is standard

// Initial power level in dBm.  Use -18 to +13 for W/CW, -2 to +20 for HW/HCW:
static const int8_t DEF_TX_POWER = 13;

// Target RSSI for auto-tuning, 0 is disable auto-tuning, -75 typical conservative
static const int8_t DEF_TGT_RSSI = -75;

// Node ID and Gateway ID.  Gateway is usually 1.  Node between 2 and 254.
// 255 is broadcast (RadioHead => RH_BROADCAST_ADDRESS).
static const uint8_t DEF_NODE_ID = 2;
static const uint8_t DEF_GATEWAY_ID = 1;

// Network octets, akin to IP address but with an extra subnet (as the 4 octets
// define a subnet, with node addressing within this).
// Need at least 2 octets to be non-zero, so will have 3rd and 4th begin at 1.
static const uint8_t DEF_NETWORK_ID_O1 = 0;  //0 to 254
static const uint8_t DEF_NETWORK_ID_O2 = 0;  //0 to 254
static const uint8_t DEF_NETWORK_ID_O3 = 1;  //1 to 254 by convention
static const uint8_t DEF_NETWORK_ID_O4 = 1;  //1 to 254 by convention

// AES 128b encryption key, shared amongst nodes.  Must be 16 chars/bytes,
// chars ASCII 32 - 126 (space, symbols, letters, numbers).
static const uint8_t KEY_LENGTH = 16;
static const uint8_t DEF_ENCRYPT_KEY[KEY_LENGTH] =
        {'C','H','A','N','G','E','_','M','E','_','P','L','E','A','S','E'};

static const uint32_t SERIAL_BAUD = 115200;

// config whether node can sleep
static const bool SLEEP_ENABLED = true;
bool canSleep = SLEEP_ENABLED;   // used at runtime if SLEEP_ENABLED

// Default meter LED impulses per kWh.  Usually 1000, 3200, or 3600.  Must
// be between 1 and 60,000.  All energy values communicated and displayed by
// the meternode are in watt-hours (Wh), although internal storage is a simple
// impulse count.
static const uint16_t DEF_METER_IMP_PER_KWH = 1000;

// Meter interval resolution in seconds.  This sets the period (max 255s) over
// which reads are accumulated into a single 'reading' - e.g. at 5s a read entry
// will represent 5s of reads (not less, sometimes more with sleep causing
// processing latency). Setting this to 0 will disable intervals, there will be
// one entry per read.
// The product of the meter interval and number of interval entries per meter
// update message should  be significantly less than the 'node dark' threshold
// set at the gateway.
static const uint8_t DEF_METER_INT_RES_SEC = 60;

// *****************************************************************************
//    General Init - Pins
// *****************************************************************************

static const uint8_t RADIO_INTERRUPT_PIN = 2;   // IC4
                                                // uses 328P interrupt 0

static const uint8_t RADIO_SS_PIN = 10;         // IC16
                                                // HIGH is off, LOW on

static const uint8_t PR_INTERRUPT_PIN = 3;      // IC5
                                                // uses 328P interrupt 1

static const uint8_t PUCK_LED_PIN = 4;          // IC6

static const uint8_t RTC_SS_PIN = 7;            // IC13
                                                // HIGH is off, LOW on

static const uint8_t BUTTON_PIN = 6;            // IC12
                                                // auxiliary button

static const uint8_t VIN_DIV_PIN = A0;          // IC23

static const uint8_t CT_CLAMP_PIN = A1;         // IC24

// *****************************************************************************
//    General Init - General Variables
// *****************************************************************************

// variable to hold MCU reset cause
uint8_t resetFlags __attribute__ ((section(".noinit")));

uint32_t btnEventStartMillis = 0;   // button on start time in millis
uint32_t btnFunctionTimer = 0;      // used to time button functions
bool btnAdjustMode = false;         // whether adjustment mode is active

// Message delays are effectively a minimum, and are approximate due to sleep.
// In practice, if meter LED pulses frequently enough to trigger PR interrupt
// at least every few seconds then variances will be slight.

// Seconds delay between sending out instruction request messages, and checking
// for a response.
static const uint16_t DEF_GINR_MSG_INTERVAL_SEC = 600;
uint16_t ginrMsgIntervalSec = DEF_GINR_MSG_INTERVAL_SEC;
uint16_t tmpGinrPollPeriod = 0;

// seconds delay between sending out clock sync ping request messages. Also
// fires at startup.
static const uint16_t PING_MSG_INTERVAL_SEC = 900;      // 15m

// global temporary variables, used somewhat arbitrarily vs local static vars
char tmpStr[40] = "";
uint32_t tmpInt = 0ul;
uint32_t tmpTime = 0ul;

// buffer for serial input/output, serial buffer position pointer
static const uint8_t SERIAL_IN_BUFFER_SIZE = 40;
char serInBuff[SERIAL_IN_BUFFER_SIZE] = "";
uint8_t serialBuffPos = 0;

// *****************************************************************************
//    General Init - Config Vars
// *****************************************************************************

// Config Variables (corresponding defaults are defined above with DEF_*).  Can
// be changed with serial commands and are saved to EEPROM.
LogLev cfgLogLevel = DEF_LOG_LEVEL;
uint8_t cfgPuckLEDRate = 0;
uint16_t cfgPuckLEDTime = 0;
int8_t cfgTXPower = 0;
int8_t cfgTgtRSSI = 0;
uint8_t cfgNodeId = 0;
uint8_t cfgGatewayId = 0;
uint8_t cfgNetworkId1 = 0;
uint8_t cfgNetworkId2 = 0;
uint8_t cfgNetworkId3 = 0;
uint8_t cfgNetworkId4 = 0;
uint8_t cfgEncryptKey[KEY_LENGTH] =
        {'\0','\0','\0','\0','\0','\0','\0','\0','\0','\0','\0','\0','\0',
        '\0','\0','\0'};
uint16_t cfgMeterImpPerKwh = 0;
uint8_t cfgMeterInterval = 0;

// *****************************************************************************
//    General Init - Logging
// *****************************************************************************

// Serial event/status logging output prefixes
static const char LOG_ERROR_LBL[] PROGMEM = "ERROR";
static const char LOG_WARN_LBL[] PROGMEM = "WARN";
static const char LOG_INFO_LBL[] PROGMEM = "INFO";
static const char LOG_DEBUG_LBL[] PROGMEM = "DEBUG";

// *****************************************************************************
//    General Init - Commands (Serial)
// *****************************************************************************

// Abbreviated vs earlier revisions to save progmem, reference online

// Serial command (RX) strings.

// help
static const char SER_CMD_HELP[] PROGMEM = "HELP";

// sleep toggle
static const char SER_CMD_SLEEP[] PROGMEM = "Z";

// CT Clamp toggle
static const char SER_CMD_CT_TOGGLE[] PROGMEM = "CTCL";

// dump meter state to console
static const char SER_CMD_DUMP[] PROGMEM = "DUMP";

// reset EEPROM config to defaults
static const char SER_CMD_RCFG[] PROGMEM = "RCFG";

// print/set time (set with TIME=[time as epoch])
static const char SER_CMD_TIME[] PROGMEM = "TIME";

// print/set loglevel (set with LOGL=[log level])
static const char SER_CMD_LOGL[] PROGMEM = "LOGL";

// print/set encryption key (set with EKEY=[key])
static const char SER_CMD_EKEY[] PROGMEM = "EKEY";

// print/set network id (set with NETI=[network id])
static const char SER_CMD_NETI[] PROGMEM = "NETI";

// print/set gateway id (set with GWID=[gateway id])
static const char SER_CMD_GWID[] PROGMEM = "GWID";

// print/set node id (set with NOID=[node id])
static const char SER_CMD_NOID[] PROGMEM = "NOID";

// print/set target rssi for auto-tuning (set with TRSS=[target RSSI -100 to 0
// (0=disable)])
static const char SER_CMD_TRSS[] PROGMEM = "TRSS";

// print/set transmission power (set with TXPW=[tx power in dBi])
static const char SER_CMD_TXPW[] PROGMEM = "TXPW";

// print/set meter value (set with MTRV=[meter value])
static const char SER_CMD_MTRV[] PROGMEM = "MTRV";

// print/set meter impulse per kWh rate (set with MTRR=[impulse count])
static const char SER_CMD_MTRR[] PROGMEM = "MTRR";

// print/set meter interval (set with MTRI=[meter interval in sec])
static const char SER_CMD_MTRI[] PROGMEM = "MTRI";

// toggle test mode
static const char SER_CMD_TEST[] PROGMEM = "TEST";

// print/set puck LED rate (set with LEDR=[rate per meter LED])
static const char SER_CMD_LEDR[] PROGMEM = "LEDR";

// print/set puck LED time (set with LEDT=[time in millis])
static const char SER_CMD_LEDT[] PROGMEM = "LEDT";

// Array of commands, used to print list on help or input
const char* const SER_CMDS[] PROGMEM = {
        SER_CMD_HELP, SER_CMD_SLEEP, SER_CMD_CT_TOGGLE,
        SER_CMD_DUMP, SER_CMD_RCFG, SER_CMD_TIME, SER_CMD_LOGL, SER_CMD_EKEY,
        SER_CMD_NETI, SER_CMD_GWID, SER_CMD_NOID, SER_CMD_TRSS, SER_CMD_TXPW,
        SER_CMD_MTRV, SER_CMD_MTRR, SER_CMD_MTRI, SER_CMD_TEST, SER_CMD_LEDR,
        SER_CMD_LEDT};

// *****************************************************************************
//    General Init - Radio Message Types
// *****************************************************************************

// Meter Rebase
static const char RMSG_MREBASE[] PROGMEM = "MREB";

// Meter Update with current
static const char RMSG_MUPC[] PROGMEM = "MUPC";

// Meter Update without current
static const char RMSG_MUP_[] PROGMEM = "MUP_";

// Instruction Request to Gateway
static const char RMSG_GINR[] PROGMEM = "GINR";

// Request from Gateway to temporarily increase GINR polling rate
static const char RMSG_GITR[] PROGMEM = "GITR";

// Clock Sync Ping Request to Gateway
static const char RMSG_PREQ[] PROGMEM = "PREQ";

// Clock Sync Ping Response from Gateway
static const char RMSG_PRSP[] PROGMEM = "PRSP";

// Meter instruction (from gateway) to set meter value
static const char RMSG_MVAI[] PROGMEM = "MVAI";

// Meter instruction (from gateway) to set meter interval
static const char RMSG_MINI[] PROGMEM = "MINI";

// Meter instruction (from gateway) to set puck LED
static const char RMSG_MPLI[] PROGMEM = "MPLI";

// 'no op' Meter instruction (from gateway)
static const char RMSG_MNOI[] PROGMEM = "MNOI";

// General purpose message (can broadcast)
static const char RMSG_GMSG[] PROGMEM = "GMSG";

// *****************************************************************************
//    Battery and Voltage Divider
//
//    Voltage divider is [VBatt <> R1 <> VIN_DIV_PIN <> R2 + 0.1uF cap <> GND]
//    Doesn't matter if R1 > R2 or vice versa.  Needs to be sized to scale
//    down voltage on pin to < 3.3V; e.g. for 5V VBatt VIN_DIV_RSCALE_MULT
//    should be >= 2. Will only work with regulator in place as
//    needed for accurate voltage measurement/scaling from 0 to 1023 at pin.
//
// *****************************************************************************

// Analogue reading to voltage divisor constant (1024/3.3V),
// result gives voltage reading at pin:
static const float VIN_DIV_VOLT_DIVISOR = 310.3f;

// Multiplier to scale voltage at pin to actual voltage upstream of voltage
// divider. Formula is (1/(R2/(R1+R2))) => 3.7 with R1=2.7M, R2=1M, 4 with
// R1=3M, R2=1M
static const float VIN_DIV_RSCALE_MULT = 3.7f;

// correction factor multipler, set by comparing with voltmeter.  Then * 1000 to
// get millivolts.
uint16_t VIN_DIV_CORRECT_MULT = 1000;

// last battery (or VIN) voltage reading in millivolts (to give some precision
// without a float)
uint16_t vinVoltageMV = 0;


// *****************************************************************************
//    CT Clamp
//
//    Uses YHDC SCT-013-000 CT, 100A maximum current
//    Using EMonLib for RMS calc etc (for now)
//
//    22 Ohm burden resistor used to give voltage proportionate to CT clamp's
//    secondary coil voltage.  Can measure up to 97A (23.3kW @ 240V).
//
//    Pmax=(240 * 3.3 * 2000) / (2 *sqrt(2) * 22) = 23.3kW
//
//    Expect 0.935 Vrms, 2.612 V peak-peak
//
//    Voltage divider is 2 * 470K
//
//    WARNING: do not unplug CT clamp from node while it's connected to a 'live
//    wire'. Apparently diode in clamp offers some protection but don't risk it.
//
// *****************************************************************************
EnergyMonitor emon1;
static const float CT_IRMS_CORRECT_MULT = 111.1;
static const float CT_AC_VOLTAGE = 230.0;
static const double CT_IRMS_HIGH_PASS = 0.3;  // seems unreliable below 0.3 A
static const int16_t CT_NUM_SAMPLES = 1480;   // proportionate to AC cycle, freq

// *****************************************************************************
//    Radio Init
//
//    All message-driven request/response interactions are logically
//    asynchronous; but implemented by RadioHead via synchronous send/ACK
//    message pairs. Messaging initiated by client node to facilitate long sleep
//    periods.  As such, the gateway needs to queue any commands or updates for
//    meter nodes.  Max message data length is 60 *bytes*, with no
//    recognition of payload elements as anything other than a big 'string'.
//    E.g. an uint32_t of 2,000,000,000 will be 80b/10B not 32b/4B.
//
// *****************************************************************************

static const float RADIO_FREQ = 915.0f;

// Modem config per RadioHead docs.  Note that lower rates (strangely) are
// unreliable with latest board.  FS seems most reliable.
//
// From FSK_Rb9_6Fd19_2 through to FSK_Rb125Fd125 work well (could go higher).
// Use fastest rate that yields acceptable range and reasonably low TX power
// (unless running on DC adapter and not concerned with RF 'noise').

//Using FSK, Whitening, bit rate = 9.6kbps, modulation frequency = 19.2kHz.
// static const RH_RF69::ModemConfigChoice MODEM_CONFIG = RH_RF69::FSK_Rb9_6Fd19_2;
static const RH_RF69::ModemConfigChoice MODEM_CONFIG = RH_RF69::FSK_Rb4_8Fd9_6;
// static const RH_RF69::ModemConfigChoice MODEM_CONFIG = RH_RF69::FSK_Rb2_4Fd4_8;
// static const RH_RF69::ModemConfigChoice MODEM_CONFIG = RH_RF69::FSK_Rb2Fd5;
// static const RH_RF69::ModemConfigChoice MODEM_CONFIG = RH_RF69::GFSK_Rb4_8Fd9_6;

// Transmit and Receive timeouts (millis).  Long timeouts can block processing
//  if gateway not up.  Erratic if > 1000.  Varied up to x2 randomly.
//  HP - 300/400 OK
//  LP - 500/2/800 OK @ FSK_Rb2Fd5
static const uint16_t TX_TIMEOUT = 500;
static const uint8_t TX_RETRIES = 3;
static const uint16_t RX_TIMEOUT = 1000;

// Radio Driver and Message Manager
RH_RF69 radio(RADIO_SS_PIN, RADIO_INTERRUPT_PIN);
RHReliableDatagram msgManager(radio, cfgNodeId);

// Last message RSSI (received signal strength indicator).  0 is highest, -100
// is lowest.
int8_t lastRSSIAtNode = 0;
int8_t lastRSSIAtGateway = 0;
// average RSSI as advised by gateway since TX power last set
int8_t averageRSSIAtGateway = 0;

// RSSI target tolerance range, outside this will cause TX Power to be
// adjusted
static const uint8_t TX_POW_RSSI_TOLERANCE = 10;

// minimum interval to check RSSI, auto-tune TXPow
static const uint16_t TX_POW_CHECK_INTERVAL_SEC = 60;

// number of consecutive TX failures before TXPow incremented
static const uint8_t TX_POW_MAX_FAILS_TO_ADJ = 3;

// if txConsFailCount >= TX_POW_MAX_FAILS_TO_ADJ will increase TX power
int8_t txConsFailCount = 0;

// radio/node Id of last message sender
uint8_t lastMsgFrom = 0;

// Intermediate string buffer for message contents.  Used as easier to work with
// than byte buffer.  KEY_LENGTH 'fudge factor' added as while length is fixed,
// an accidental overflow can be caught and handled through validation instead
// of creating an actual overflow.
char msgBuffStr[RH_RF69_MAX_MESSAGE_LEN + KEY_LENGTH] = "";

// Actual buffer used to pass payload to/from the RadioHead library.
uint8_t radioMsgBuff[RH_RF69_MAX_MESSAGE_LEN] = "";


// *****************************************************************************
//    Metering Init
//
// *****************************************************************************

// Test settings.  Toggled via TESTMODE serial commmand, simulates meter LED
// pulses at TEST_METER_IMP_INTERVAL (minimum delay between pulses) with
// TEST_METER_IMP_TIME setting the duration of the pulse itself (pulse width).
bool testMode = false;
static const uint16_t TEST_METER_IMP_INTERVAL = 1000;     // millis
static const uint16_t TEST_METER_IMP_TIME = 10;           // millis
bool testPulseOn = false;
uint32_t whenTestPulseChange = 0ul;                         //millis

// Align reads (used to align intervals to mm:00 when setting time)
bool alignReads = true;
uint32_t alignReadingFrom = 0ul; // timestamp

// A Wh base value is used to allow the meter's impulse count values to be
// cumulative, but small.  These are converted to Wh and added the base value
// for display or communication.
uint32_t meterBaseValue = 0ul;    // Wh

// Maximum meter base value => 3 billion Wh (3GWh).
// Maximum meter value => 4.2 billion Wh (4.2GWh).
// UL type will overflow at ~4.3 billion.
static const uint32_t METER_MAX_BASE_VALUE = 3000000000ul;
static const uint32_t METER_MAX_VALUE = 4200000000ul;

// max of 255 with unsigned short 'pointers'; little benefit in making
// longer than ~10 as is redundant on message send
static const uint8_t METER_ENTRY_BUFFER_LEN = 10;

typedef enum {
    entryNull = 0,
    entryOpen = 1,          // interval open, accepts new reads
    entryClosed = 2,        // closed, interval expired, ready to send
    entrySent = 3           // entry sent
} MeterEntryState;
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
void loop() {
    /*
        Do processing, comms on a prioritised basis before sleeping.
        Some functions are run multiple times (rather than a single loop)
        as they involve human input and need to allow time for that input
    */

    static uint8_t doEvery = 0;

    for (doEvery = 1; doEvery <=6; doEvery++){
        // do every time
        checkSerialInput();
        checkButton();

        checkTestMode();
        wdt_reset();

        // do processing if not in middle of serial input
        if (serialBuffPos == 0)
            checkPuckLEDState();

        if (serialBuffPos == 0 && doEvery % 2 == 1)
            checkMeterTimer();

        else if (serialBuffPos == 0 && doEvery == 2)
            checkGWInstTimer();

        else if (serialBuffPos == 0 && doEvery == 4)
            checkGWClockSync();

        else if (serialBuffPos == 0 && doEvery == 6)
            sleepNode();
    }
}

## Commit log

2017-10-18 Baseline Commit from private repo
    [MM_node-B.Cu.gbl, MM_node-B.Mask.gbs, MM_node-B.SilkS.gbo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]
2017-12-01 R7, minor doc edits
    [MM_node.sch]
